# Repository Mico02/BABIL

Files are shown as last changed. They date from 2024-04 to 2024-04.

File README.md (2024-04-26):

# BABIL
A fully offline, autonomous, real-time captioning and translation device, running on a Raspberry Pi 
## Bill of Materials
| **Component** | **Quantity** | **Where to get** |
|---|---|---|
| Raspberry Pi 4B/5 8GB Ram | 1 | [Link](https://www.raspberrypi.com/products) |
| Raspiaudio Mic Ultra+ | 1 | [Link](https://raspiaudio.com/product/ultra/) |
| Samsung FIT Plus 256GB USB 3.1 | 1 | [Link](https://www.amazon.com/Samsung-MUF-256AB-AM-Plus-256GB/dp/B07D7Q41PM?th=1) |
| 1.51inch Transparent OLED | 1 | [Link](https://www.amazon.com/1-51inch-Transparent-OLED-Display-Independent/dp/B0B8MQJKB5) |
| 24-pin 0.5mm FFC/FPC Extender | 1 | [Link](https://www.adafruit.com/product/4524) |
| 24-pin eInk/ePaper Extension  Cable 0.5mm Pitch - 25cm Long | 1 | [Link](https://www.adafruit.com/product/4230) |
| IP5328P Power Supply Board | 1 | |
| 10Ah Battery-Adafruit | 1 | [Link](https://www.digikey.com/en/products/detail/adafruit-industries-llc/5035/14625568)  |
| USB-A to USB-C power cable | 1 | Can find from many vendors |
| User Interface PCB | 1 | See "Hardware" folder in repo for PCB files |
| Frame: Back Piece | 2 | See "Hardware" folder in repo for 3D print files |
| Frame: Sides (Left and Right) | 1 (each) | See "Hardware" folder in repo for 3D print files |
| Frame: Front wire bridge | 1 | See "Hardware" folder in repo for 3D print files |
| Frame: Front | 1 | See "Hardware" folder in repo for 3D print files |
| Frame: Display holder | 1 | See "Hardware" folder in repo for 3D print files |
| PLA Gloop | 1 | [Link](https://www.3dgloop.com/shop/pla-gloop) |
| 15mm Focal Length Lens | 1 | |

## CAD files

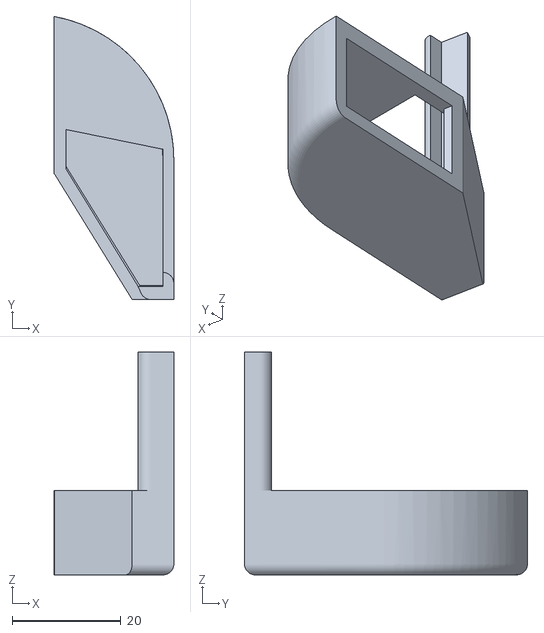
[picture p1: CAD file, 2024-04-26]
hardware/Frame/Display.STL
22.0 x 52.0 x 40.9

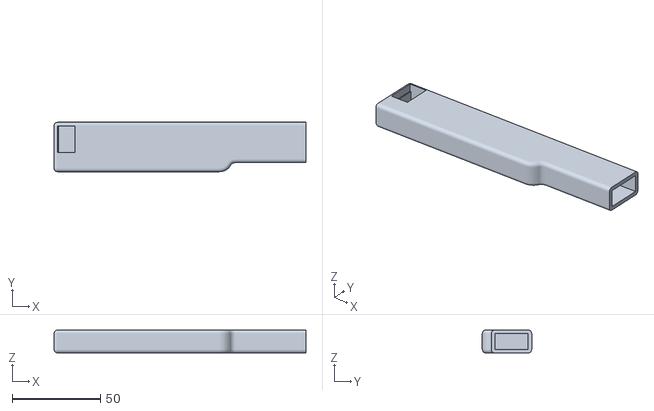
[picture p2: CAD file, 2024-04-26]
hardware/Frame/RightSide.STL
142.5 x 28.0 x 13.0

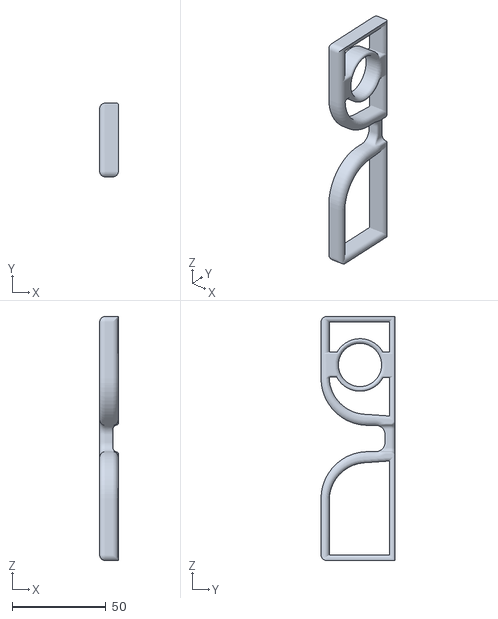
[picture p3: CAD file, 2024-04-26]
hardware/Frame/Front.STL
10.00 x 39.4 x 130.0

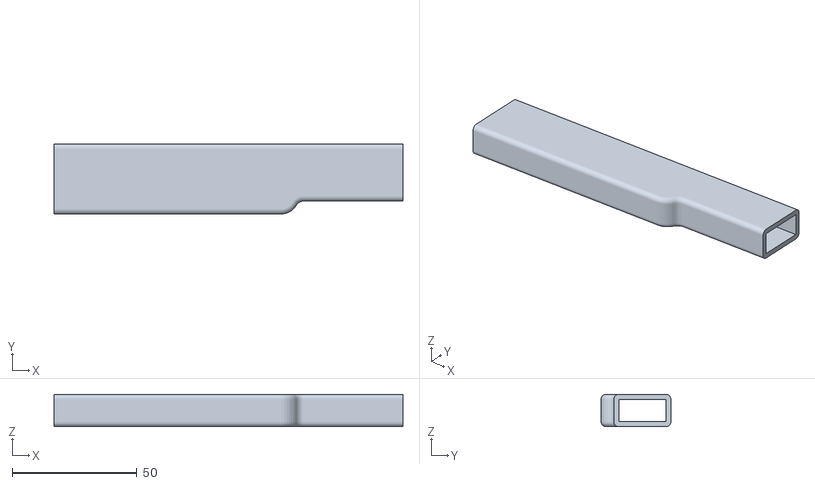
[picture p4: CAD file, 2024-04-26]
hardware/Frame/LeftSide.STL
140.0 x 28.0 x 13.0

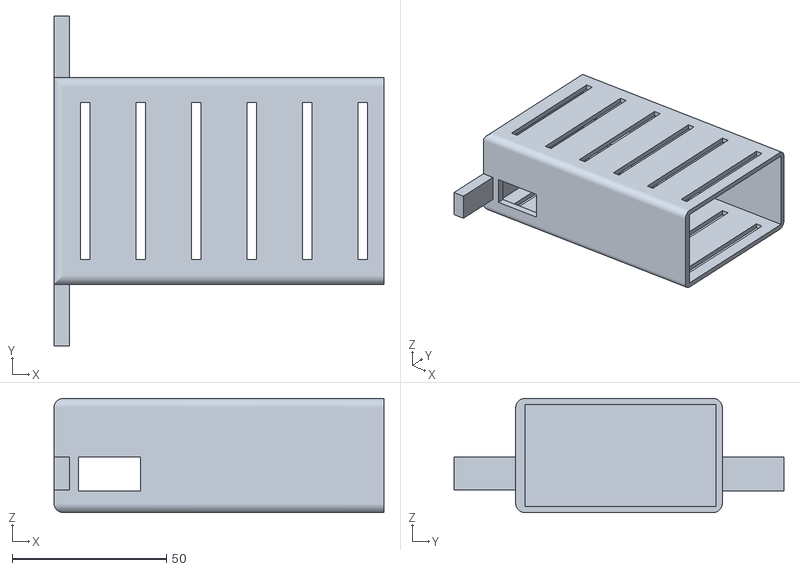
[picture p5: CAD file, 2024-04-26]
hardware/Frame/Back.STL
107.0 x 107.0 x 37.0

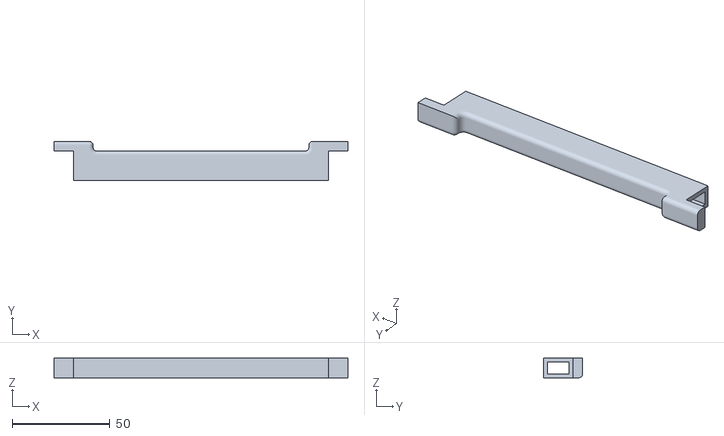
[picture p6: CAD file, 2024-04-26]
hardware/Frame/FrontWire.STL
150.0 x 20.0 x 10.0

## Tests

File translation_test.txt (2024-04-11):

-- WHEN USING TEXT INPUT --
(no buffer)
Parents were worried about what to eat for their children after the Sande's toxic milk powder incident
Parents were worried about what to feed their children after the Sanlu's toxic milk powder incident exposed 17.6%
A good friend is someone who can share happiness and sorrow with you
A good friend is someone who can share happiness and sorrow with you 0%
I appreciate your advice. It helped me get along
I appreciate your advice. It helped me get along with my classmates 25%
This is his first e-mail conversation with a pen friend 
This is his first e-mail conversation with a pen friend 0%
When we were playing by the pool, that naughty boy deliberately pushed me into the water
When we were playing by the pool, that naughty boy deliberately pushed me into the water 0%
Love doesn't bore you. The longer you spend, the more fun you get 
Hobby doesn't bore you. The longer you spend, the more fun you get 15.3%

AVG = 9.7%

--- WHEN USING SPEECH INPUT (speech -> transcription -> translator) ---
(10 word buffer)
1. In the mountains, after the story of the powder came to light, the doorman of the parents What to eat and worry about (在山路有来奶粉事件曝光后家长门卫该给孩子吃什么而忧虑)  //This should be redone
After Sanlu's toxic milk powder came to light, the parents worry about What to feed their children(在三鹿有毒奶粉事件曝光后家长们为该给孩子吃什么而忧虑)
HTER for transcription = 19.2%
HTER for translation = 41.2%

2. Good friends are those who share with you joy and sorrow (好好朋友就是和你分享快乐和忧伤的人)
Good friends are those who share with you joy and sorrow(好朋友就是能和你分享快乐和忧伤的人)
HTER for transcription = 11.8%
HTER for translation = 0

3. I am pleased to thank you for your advice. He helped me Get along with your classmates(我很高兴感激你的建议他帮助了我与同学融洽相处)
I really thank you for your advice. It helped me Get along with my classmates(我很感激你的建议他帮助了我与同学们融洽相处)
HTER for transcription = 19%
HTER for translation = 33.3%
4. This is the first time he has spoken with a pen friend by e-mail (这是他第一次用电子邮件与笔友交流)
This is the first time he has spoken with a pen friend by e-mail(这是他第一次用电子邮件与笔友交流)
HTER for transcription = 0
HTER for translation = 0

5. When we played by the pool The naughty boy deliberately pushed me down into the water (的我们在游泳池边玩的时候淘气的男孩故意把我推倒了水里)
When we played by the pool The naughty boy deliberately pushed me into the water (当我们在游泳池边玩的时候那个淘气的男孩故意把我推到了水里)
HTER for transcription = 14.3%
HTER for translation = 6.7%

6. A hobby is not to make you tired of your input The longer the time, the fun, the reading(爱好是不会让你感到厌倦的你投入的时间越长乐趣阅读)
A hobby is not make you tired of, you invest The longer the time, the more fun you get(爱好是不会让你感到厌倦的你投入的时间越长乐趣越多)
HTER for transcription = 8.3%
HTER for translation = 31.6%

AVG HTER for transcription = 12.1%
AVG HTER for translation = 18.8%

(5 word buffer)
1. There's a poison, powdered milk incident After exposure, parents, gatekeepers Children, eat what, and worry (在有毒奶粉事件曝光后家长门卫该给孩子吃什么而忧虑)
2. Persons Okay, good friend You share joy and sorrow (好好朋友就是能和你分享快乐和忧伤的人)
3. I'm grateful to you He helped me Get along with your classmates(我很感激你的建议他帮了我与同学融洽相处)
4. This is him, for the first time E-mail and comparison(这是他第一次用电子邮件与比交流)
5. When we were at the pool by The time of play, the naughty Boy, deliberately push me down Who's there (当我们在游泳池边玩的时候那淘气的男孩故意把我推倒到了谁里)
6. A hobby, yes. No, you I'm tired of talking about input Reading The longer the time, the more fun(爱好是不会让你感到厌倦的说投入的时间越长乐趣阅读)

-- SPEED TEST --

*****WE ARE SAYING WORDS/PHRASE THE FILL THE BUFFER COMPLETLY*****
-- USING A ONE WORD BUFFER --
SPEED: 1.95s, 2.2s, 2s -> avg = 2.05 seconds

-- USING A 5 WORD BUFFER -- 
SPEED: 4.075s, 2.75s, 1.28s, 1.2s, 4.47s, 2.3s -> AVG = 2.67s

NOTES: IT SEEMS THAT THE SPEED OF THE TRANSLATION GETS BETTER OVER MULTIPLE TRIES,
WHEN RUNNING THE PROGRAM AT FIRST, IT SEEMS TO HAVE A DELAY AROUND 3-4s, AFTER 
TESTING AFTER THE FIRST, THE TRANSLATOR SEEMS TO SPEED UP AND GET SPEEDS AROUNDS
2-3s.

-- USING A 10 WORD BUFFER -- 
SPEED: 4.2s, 3.5s, 3.9s, 2.9s -> AVG = 2.9s

NOTES: IT EXHIBITS THE SAME PHENOMENA AS THE WHNE USING THE 5 WORD BUFFER AND DOING MULITPlE RUNS

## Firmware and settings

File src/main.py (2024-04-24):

import sys
import threading
from transcription import Transcriber
from translation import Translator
from display import OLEDDisplay
from button import ButtonHandler, PowerButtonHandler


vosk_to_libre_lang_codes = {
    "en" : "en",
    "cn" : "zh", 
    "ru" : "ru", 
    "fr" : "fr", 
    "de" : "de", 
    "es" : "es", 
    "pt" : "pt", 
    "gr" : "el", 
    "tr" : "tr", 
    "vn" : "vi", 
    "it" : "it", 
    "nl" : "nl",
    "ar" : "ar",
    "ca" : "ca",
    "fa" : "fa",
    "ph" : "tl",
    "uk" : "uk",
    "sv" : "sv",
    "jp" : "ja",
    "eo" : "eo",
    "hi" : "hi",
    "cs" : "cs",
    "po" : "pl",
    "ko" : "ko"
}

lang_buffer_size = {
    "zn" : 10
}

def vosk_code_to_libre(lang_code):
    if lang_code in vosk_to_libre_lang_codes.keys():
        return vosk_to_libre_lang_codes.get(lang_code)
    else:
        print("Incorrect from language code")
        exit()

def transcribe(language, display):
    transcriber = Transcriber(language=language, display=display)
    transcriber.run()
    return

def transcribeTest(language, display):
    transcriber = Transcriber(language=language, display=display)
    transcriber.runTranscriptionTest()
    return

def translate(from_code, to_code, display):
    transcriber = Transcriber(language=from_code, display=display)
    if from_code in vosk_to_libre_lang_codes.keys():
        from_code = vosk_to_libre_lang_codes.get(from_code)
    if to_code in vosk_to_libre_lang_codes.keys():
        to_code = vosk_to_libre_lang_codes.get(to_code)
    translatator = Translator(from_code=from_code, to_code=to_code)
    if to_code in lang_buffer_size.keys():
        buffersize = lang_buffer_size.get(to_code)
    else:
        buffersize = 5
    transcriber.runWithTranslation(translatator,buffersize)
    return
def translateTest(from_code, to_code, display):
    transcriber = Transcriber(language=from_code, display=display)
    translatator = Translator(from_code=from_code, to_code=to_code)
    transcriber.runWithTranslationTest(translatator,5)
    return

def main():

    #initializing buttonhandler and power/reboot thread
    button = ButtonHandler()
    powerbutton = PowerButtonHandler()
    reboot = threading.Thread(target=button.reboot_reselect)
    power = threading.Thread(target=powerbutton.wait_for_press)
    reboot.start()
    power.start()
    #Initializing display object
    display = OLEDDisplay(font_size=10)

    #Read cmd arguements 
    mode = sys.argv[1]
    if mode == '-c':
        language = sys.argv[2]
        transcribe(language,display)
        sys.exit()
    elif mode == '-tc': 
        language = sys.argv[2]
        transcribeTest(language,display)
        sys.exit()
    elif mode == '-tt':
        from_code = sys.argv[2]
        to_code = sys.argv[3]
        phrase = sys.argv[4]
        translator = Translator(from_code,to_code)
        translator.runTest(phrase)
        sys.exit()
    else: 
        from_code = sys.argv[1]
        to_code = sys.argv[2]
        if from_code == to_code:
            transcribe(language=from_code)
            sys.exit()
        translate(from_code=from_code, to_code=to_code, display=display)
        sys.exit()
    reboot.join()
    power.join()

main()

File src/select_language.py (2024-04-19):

from button import ButtonHandler, PowerButtonHandler
from display import OLEDDisplay
import sys
import threading
import subprocess

caption_languages = {"en" : "English",
                     "cn" : "Chinese", 
                     "ru" : "Russian", 
                     "fr" : "French", 
                     "de" : "German", 
                     "es" : "Spanish", 
                     "pt" : "Portuguese", 
                     "gr" : "Greek", 
                     "tr" : "Turkish", 
                     "vn" : "Vietnamese", 
                     "it" : "Italian", 
                     "nl" : "Dutch",
                     "ar" : "Arabic",
                     "ca" : "Catalan",
                     "fa" : "Farsi",
                     "ph" : "Filipino",
                     "uk" : "Ukrainian",
                     "kz" : "Kazakh",
                     "sv" : "Swedish",
                     "jp" : "Japanese",
                     "eo" : "Esparanto",
                     "hi" : "Hindi",
                     "cs" : "Czech",
                     "po" : "Polish",
                     "uz" : "Uzbek",
                     "ko" : "Korean",
                     "br" : "Breton",
                     "gu" : "Gujarati"} 
from_translation_languages = {"en" : "English",
                            "cn" : "Chinese", 
                            "ru" : "Russian", 
                            "fr" : "French", 
                            "de" : "German", 
                            "es" : "Spanish", 
                            "pt" : "Portuguese", 
                            "gr" : "Greek", 
                            "tr" : "Turkish", 
                            "vn" : "Vietnamese", 
                            "it" : "Italian", 
                            "nl" : "Dutch",
                            "ar" : "Arabic",
                            "ca" : "Catalan",
                            "fa" : "Farsi",
                            "ph" : "Filipino",
                            "uk" : "Ukrainian",
                            "sv" : "Swedish",
                            "jp" : "Japanese",
                            "eo" : "Esparanto",
                            "hi" : "Hindi",
                            "cs" : "Czech",
                            "po" : "Polish",
                            "ko" : "Korean"}

to_translation_languages = {"en" : "English",
                            "sq" : "Albanian",
                            "ar" : "Arabic",
                            "az" : "Azerbaijani",
                            "bn" : "Bengali",
                            "bg" : "Bulgarian",
                            "ca" : "Catalan",
                            "zh" : "Chinese",
                            "zt" : "Chinese (traditional)",
                            "cs" : "Czech",
                            "da" : "Danish",
                            "nl" : "Dutch",
                            "eo" : "Esperanto",
                            "et" : "Estonian",
                            "fi" : "Finnish",
                            "fr" : "French",
                            "de" : "German",
                            "el" : "Greek",
                            "he" : "Hebrew",
                            "hi" : "Hindi",
                            "hu" : "Hungarian",
                            "id" : "Indonesian",
                            "ga" : "Irish",
                            "it" : "Italian",
                            "ja" : "Japanese",
                            "ko" : "Korean",
                            "lv" : "Latvian",
                            "lt" : "Lithuanian",
                            "ms" : "Malay",
                            "nb" : "Norwegian",
                            "fa" : "Farsi",
                            "pl" : "Polish",
                            "pt" : "Portuguese",
                            "ro" : "Romanian",
                            "ru" : "Russian",
                            "sr" : "Serbian",
                            "sk" : "Slovak",
                            "sl" : "Slovenian",
                            "es" : "Spanish",
                            "sv" : "Swedish",
                            "tl" : "Filipino",
                            "th" : "Thai",
                            "tr" : "Turkish",
                            "uk" : "Ukrainian",
                            "ur" : "Urdu",
                            "vi" : "Vietnamese"}
    

def select_device_mode(buttons: ButtonHandler, display: OLEDDisplay):
    modes = ["Captioning", "Translation"]
    selected = False
    option = [0]
    idx = 0
    while not selected:
        display.displayWord(modes[idx])
        buttons.selectOption(option)
        if option[0] == ButtonHandler.RIGHT:
            idx = (idx + 1) % len(modes)
        elif option[0] == ButtonHandler.LEFT:
            idx = (idx - 1) % len(modes)
        elif option[0] == ButtonHandler.SELECT:
            selected = True
        else:
            print("Error: invalid button", file=sys.err)
    return modes[idx]

def select_language(buttons: ButtonHandler, languages: dict, display: OLEDDisplay):
    idx = 0
    selected = False
    x = [0]
    lang_list = list(languages)
    while not selected: 
        display.displayWord(languages.get(lang_list[idx]))
        buttons.selectOption(x)
        if x[0] == ButtonHandler.RIGHT: #MOVE TO THE RIGHT
            idx = (idx + 1) % len(languages)
        elif x[0] == ButtonHandler.LEFT: #MOVE TO THE LEFT
            idx = (idx - 1) % len(languages)
        elif x[0] == ButtonHandler.SELECT:
            selected = True
        else:
            print("Error: invalid button", file=sys.err)
    return lang_list[idx]


powerButton = PowerButtonHandler()
buttons = ButtonHandler()
powerButtonThread = threading.Thread(target=powerButton.wait_for_press)
powerButtonThread.start()

display = OLEDDisplay(font_size=10)

mode = select_device_mode(buttons,display)
print(f"{mode} is the selected mode")
if mode == "Captioning":
    lang = select_language(buttons, caption_languages,display)
    print(f"{caption_languages.get(lang)} is the selected lang")
    powerButton.stop_waiting()
    powerButtonThread.join()
    subprocess.Popen(["python3" ,"src/main.py","-c",lang])
    print("GOODBYE")
    exit()
elif mode == "Translation":
    from_lang = select_language(buttons, from_translation_languages, display)
    print(f"{from_translation_languages.get(from_lang)} is the selected from lang")
    to_lang = select_language(buttons, to_translation_languages, display)
    print(f"{to_translation_languages.get(to_lang)} is the selected to lang")
    powerButton.stop_waiting()
    powerButtonThread.join()
    subprocess.Popen(["python3" ,"src/main.py",from_lang, to_lang])
    print("GOODBYE")
    exit()

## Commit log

2023-11-30 switched to libretranslate api
2024-01-27 modified .run() method so that it prints in close to real time
2024-01-27 set default rotation to 180º and shorted delay between words in .displayWords() method
    [display.py]
2024-02-06 added button listener for interupts
2024-02-06 added button listener thread
2024-02-06 added shutdown and reboot buttons
2024-02-06 moved thread creation to transcription class
2024-02-13 added a button listener class that can be used universally
2024-02-13 selecting language using button
2024-02-17 lots of just random experimenting with buttons
2024-02-17 rewriting the button handler/listener class
2024-02-17 removed print statements and added bouncetime for GPIO buttons
2024-02-17 added a power button class to handle the power button
2024-02-17 using threading to allow for power button to be clicked at any time
2024-02-17 removed old button listener
2024-02-20 added reboot interrupt method
    [button.py]
2024-02-20 added a button listener for the main program
2024-04-02 added the sample text and results of the translation test
2024-04-11 fixing issues with lang code mismatch
    [main.py, select_language.py]
2024-04-13 swapped buttons
2024-04-26 documenation and frame files
    [Back.STL, Display.STL, Front.STL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]
